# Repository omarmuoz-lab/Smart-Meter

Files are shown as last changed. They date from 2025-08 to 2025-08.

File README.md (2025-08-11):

# Smart Meter – Firmware & PCB Designs

This repository contains all the resources for a custom-built **Smart Meter**, including:

- **Firmware** for the embedded microcontroller.
- **PCB designs** for the hardware implementation.

The project is aimed at real-time measurement of electrical parameters such as voltage, current, active power, reactive power, apparent power, power factor, and energy consumption.

---

## 📂 Repository Structure

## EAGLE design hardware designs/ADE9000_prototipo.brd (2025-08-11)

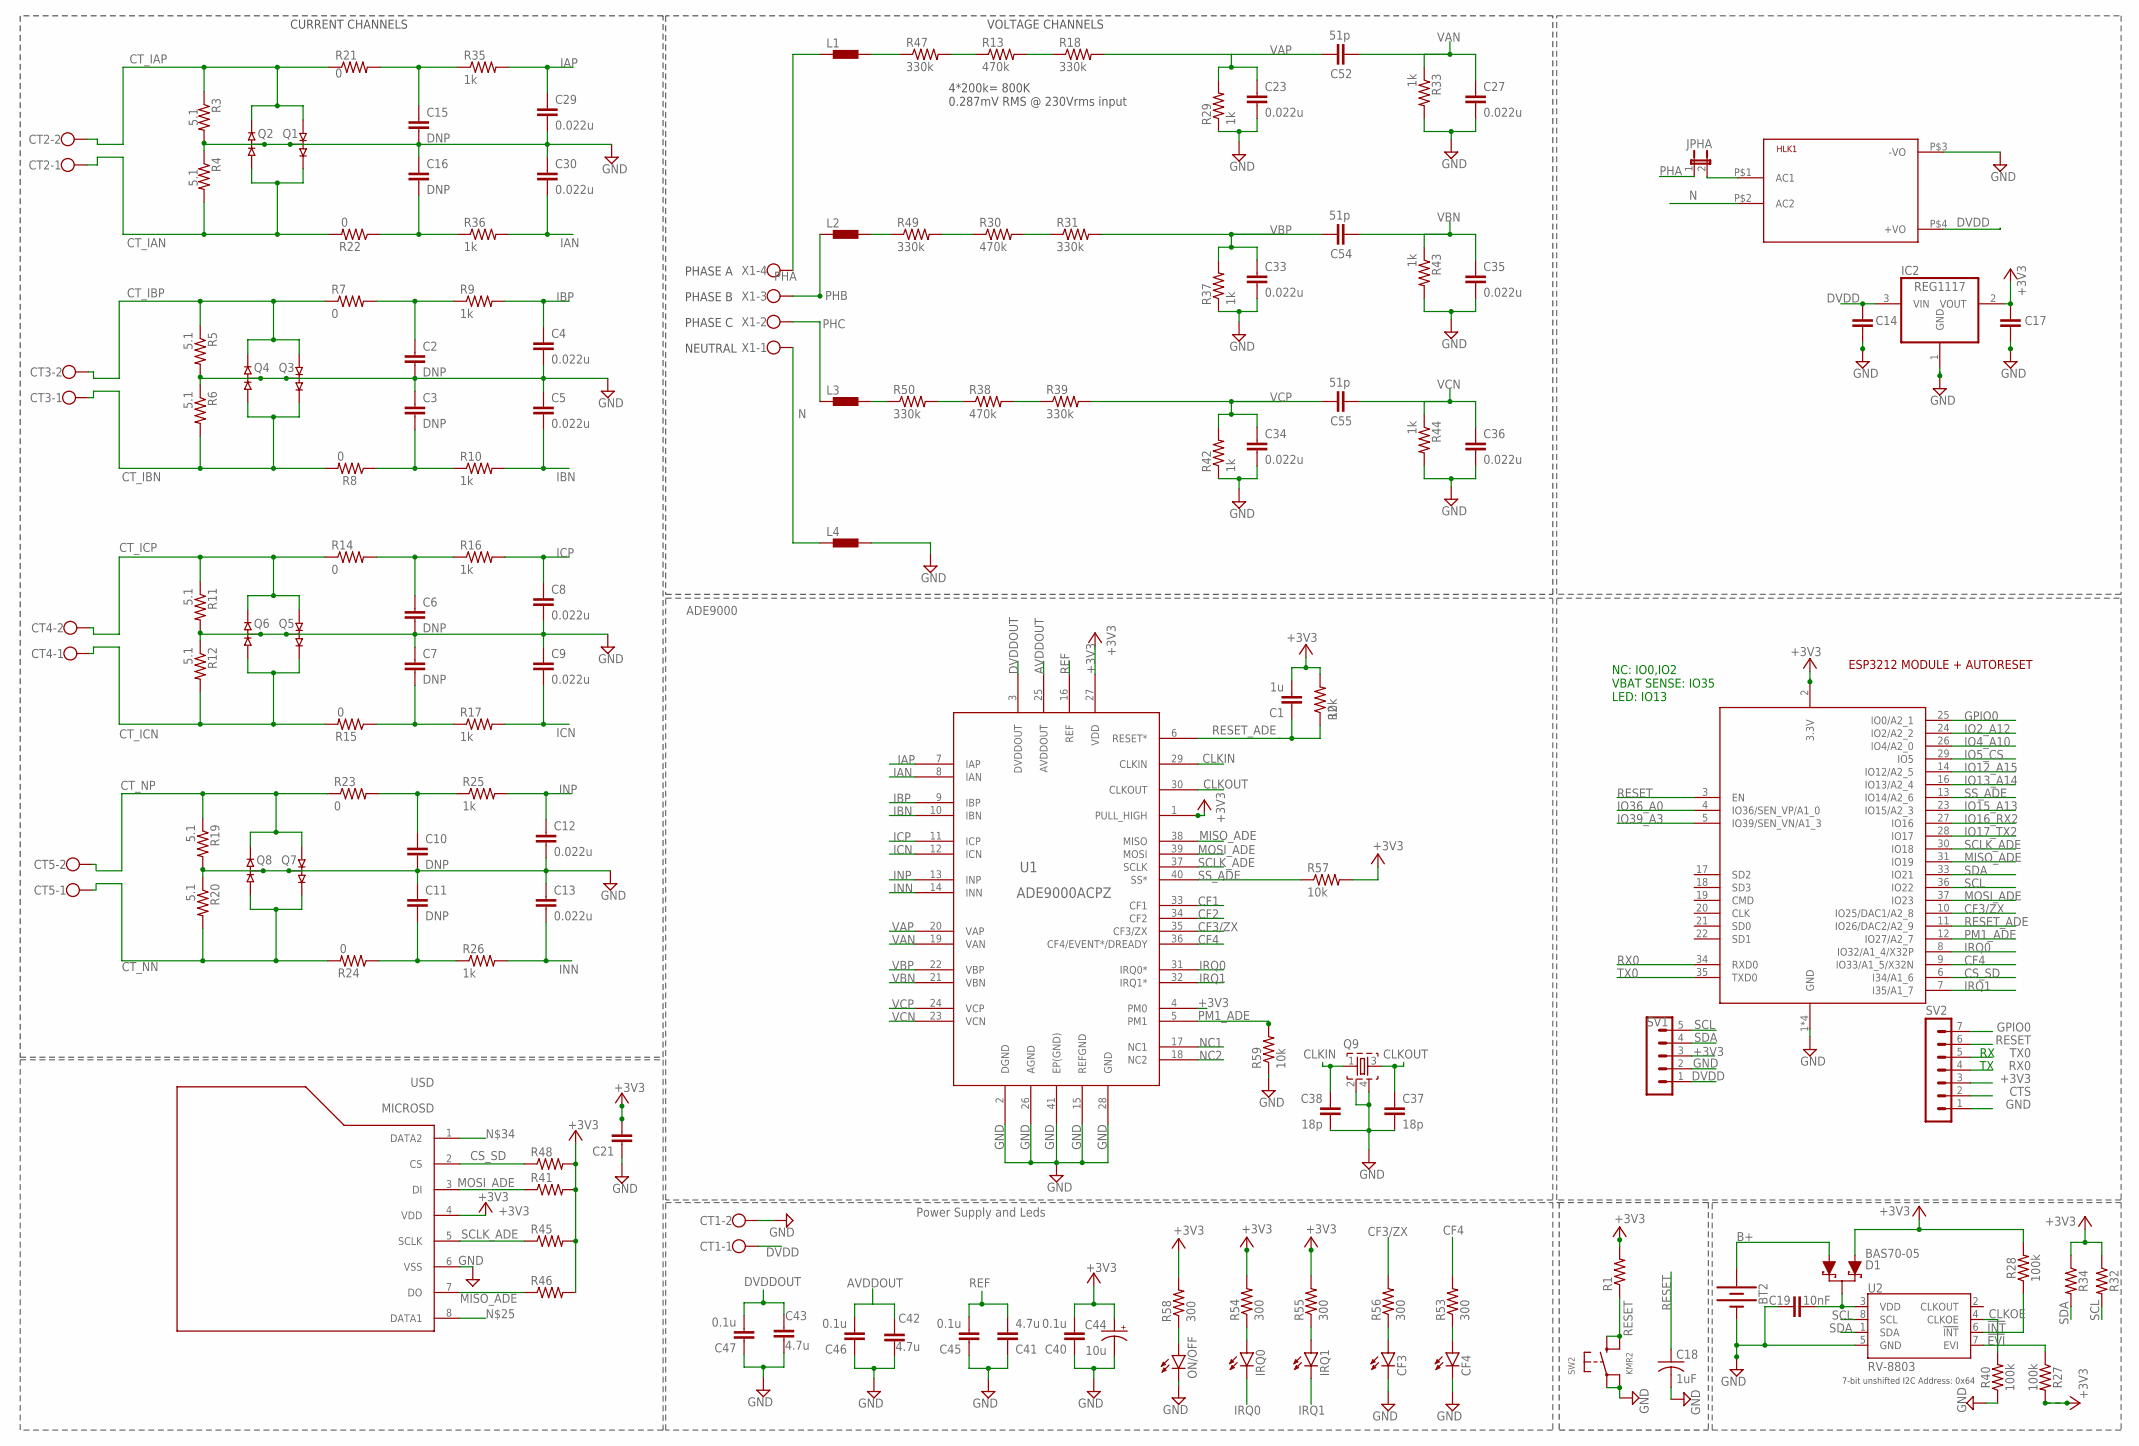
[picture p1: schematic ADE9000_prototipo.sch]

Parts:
BT2: BATTERY-12MM_SMD; BATTCON_12MM
C1: 1u; C0805
C2, C3, C6, C7, C10, C11, C15, C16: DNP; C0805
C4, C5, C8, C9, C12, C13, C23, C29, C30, C33, C34: 0.022u; C0805
C14, C17: C-EUC1206; C1206
C18: 1uF; C0805
C19: 10nF; 0603
C21, C40, C45, C46, C47: 0.1u; C0805
C27, C35, C36: 0.022u; C0603
C37, C38: 18p; C0805
C41, C42, C43: 4.7u; C0805
C44: 10u; E1,8-4
C52, C54, C55: 51p; C0603
CF3, CF4: LEDCHIPLED_1206; CHIPLED_1206
CT1, CT2, CT3, CT4, CT5: W237-102
D1: BAS70-05; SOT23-3
HLK1: HLK-PM013W; HLK-PM01
IC2: REG1117; SOT223
IRQ0, IRQ1: LEDCHIPLED_1206; CHIPLED_1206
JPHA: JP1E; JP1
L1, L2, L3, L4: 1500; M0805; DIGIKEY 490-1048-1-ND
ON/OFF: LEDCHIPLED_1206; CHIPLED_1206
Q1, Q2, Q3, Q4, Q5, Q6, Q7, Q8: MMBD4148SE; SOT23-3; DIGIKEY MMBD4148SECT-ND
Q9: ECS-245.7-12-33Q-JES-TR; SMD_4PIN_3.2X2.1; DIGIKEY XC2178CT-ND
R1, R41, R45, R46, R48: R-US_R0805; R0805
R2, R57, R59: 10k; R0805
R3, R5, R11, R19: 5.1; R0805; MFR_PART_NO_# CPF0805B5R1E1
R4, R6, R12, R20: 5.1; R0805
R7, R8, R14, R15, R21, R22, R23, R24: 0; R0805
R9, R10, R16, R17, R25, R26, R29, R35, R36, R37, R42: 1k; R0805
R13, R30, R38: 470k; R0805
R18, R31, R39, R47, R49, R50: 330k; R0805
R27, R28, R40: 100k; 0603
R32: 4.7k; 0603
R33, R43, R44: 1k; R0603
R34: 4.7KOHM-0603-1/10W-1%; 0603
R53, R54, R55, R56, R58: 300; R0805
SV1: MA05-1
SV2: MA07-1
SW2: KMR2; BTN_KMR2_4.6X2.8
U1: ADE9000ACPZ; CP_40_7; DIGIKEY ADE9000ACPZ-RLCT-ND
U2: RV-8803; RV-3028
USD: MICROSD
X1: W237-4
X4: ESP32_WROOM32_SKINNY; WROOM32_SKINNY

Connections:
!EVI: R27.1, U2.7 (EVI)
!INT: R28.1, U2.6 (!INT)
+3V3: C1.2, C17.1, C21.2, C40.2, C44.+, D1.1 (A), IC2.2 (VOUT), R1.2, R2.2, R27.2, R28.2, R32.1, R34.1, R41.2, R45.2, R46.2, R48.2, R54.2, R55.2, R57.2, R58.2, SV1.3, SV2.3, U1.1 (PULL_HIGH), U1.4 (PM0), U1.27 (VDD), USD.4 (VDD), X4.2 (3.3V)
AVDDOUT: C42.1, C46.2, U1.25 (AVDDOUT)
B+: BT2.PWR@1 (+), D1.2 (A1)
CF1: U1.33 (CF1)
CF2: U1.34 (CF2)
CF3/ZX: R56.2, U1.35 (CF3/ZX), X4.10 (IO25/DAC1/A2_8)
CF4: R53.2, U1.36 (CF4/EVENT*/DREADY), X4.9 (IO33/A1_5/X32N)
CLKIN: C38.1, Q9.1, U1.29 (CLKIN)
CLKOE: R40.2, U2.4 (CLKOE)
CLKOUT: C37.1, Q9.3, U1.30 (CLKOUT)
CS_SD: R48.1, USD.2 (CS), X4.6 (I34/A1_6)
CTS: SV2.2
CT_IAN: CT2.1, Q1.2, Q2.1, R4.2, R22.2
CT_IAP: CT2.2, Q1.1, Q2.2, R3.1, R21.1
CT_IBN: CT3.1, Q3.2, Q4.1, R6.2, R8.2
CT_IBP: CT3.2, Q3.1, Q4.2, R5.1, R7.1
CT_ICN: CT4.1, Q5.2, Q6.1, R12.2, R15.2
CT_ICP: CT4.2, Q5.1, Q6.2, R11.1, R14.1
CT_NN: CT5.1, Q7.2, Q8.1, R20.2, R24.2
CT_NP: CT5.2, Q7.1, Q8.2, R19.1, R23.1
DVDD: C14.1, CT1.1, HLK1.P$4 (+VO), IC2.3 (VIN), SV1.1
DVDDOUT: C43.1, C47.2, U1.3 (DVDDOUT)
GND: BT2.GND (-), C2.2, C3.1, C4.2, C5.1, C6.2, C7.1, C8.2, C9.1, C10.2, C11.1, C12.2, C13.1, C14.2, C15.2, C16.1, C17.2, C18.2, C19.1, C21.1, C23.2, C27.2, C29.2, C30.1, C33.2, C34.2, C35.2, C36.2, C37.2, C38.2, C40.1, C41.1, C42.2, C43.2, C44.-, C45.1, C46.1, C47.1, CF3.C, CF4.C, CT1.2, HLK1.P$3 (-VO), IC2.1 (GND), L4.2, ON/OFF.C, Q1.3, Q2.3, Q3.3, Q4.3, Q5.3, Q6.3, Q7.3, Q8.3, Q9.2, Q9.4, R3.2, R4.1, R5.2, R6.1, R11.2, R12.1, R19.2, R20.1, R29.1, R33.2, R37.1, R40.1, R42.1, R43.2, R44.2, R59.1, SV1.2, SV2.1, SW2.A, SW2.A' (P1), U1.2 (DGND), U1.15 (REFGND), U1.26 (AGND), U1.28 (GND), U1.41 (EP(GND)), U2.5 (GND), USD.6 (VSS), X4.1 (GND), X4.15 (GND), X4.38 (GND), X4.P$1 (GND)
GPIO0: SV2.7, X4.25 (IO0/A2_1)
IAN: C30.2, R36.2, U1.8 (IAN)
IAP: C29.1, R35.2, U1.7 (IAP)
IBN: C5.2, R10.2, U1.10 (IBN)
IBP: C4.1, R9.2, U1.9 (IBP)
ICN: C9.2, R17.2, U1.12 (ICN)
ICP: C8.1, R16.2, U1.11 (ICP)
INN: C13.2, R26.2, U1.14 (INN)
INP: C12.1, R25.2, U1.13 (INP)
IO2_A12: X4.24 (IO2/A2_2)
IO4_A10: X4.26 (IO4/A2_0)
IO5_CS: X4.29 (IO5)
IO12_A15: X4.14 (IO12/A2_5)
IO13_A14: X4.16 (IO13/A2_4)
IO15_A13: X4.23 (IO15/A2_3)
IO16_RX2: X4.27 (IO16)
IO17_TX2: X4.28 (IO17)
IO36_A0: X4.4 (IO36/SEN_VP/A1_0)
IO39_A3: X4.5 (IO39/SEN_VN/A1_3)
IRQ0: IRQ0.C, U1.31 (IRQ0*), X4.8 (IO32/A1_4/X32P)
IRQ1: IRQ1.C, U1.32 (IRQ1*), X4.7 (I35/A1_7)
MISO_ADE: R46.1, U1.38 (MISO), USD.7 (DO), X4.31 (IO19)
MOSI_ADE: R41.1, U1.39 (MOSI), USD.3 (DI), X4.37 (IO23)
N: HLK1.P$2 (AC2), L4.1, X1.1
unnamed: C19.2, D1.3 (C), U2.3 (VDD)
unnamed: R13.1, R47.2
unnamed: C3.2, R8.1, R10.1
unnamed: C2.1, R7.2, R9.1
unnamed: HLK1.P$1 (AC1), JPHA.2
unnamed: L3.2, R50.1
unnamed: L2.2, R49.1
unnamed: C7.2, R15.1, R17.1
unnamed: C6.1, R14.2, R16.1
unnamed: C16.2, R22.1, R36.1
unnamed: C11.2, R24.1, R26.1
unnamed: C10.1, R23.2, R25.1
unnamed: CF3.A, R56.1
unnamed: ON/OFF.A, R58.1
unnamed: IRQ0.A, R54.1
unnamed: IRQ1.A, R55.1
unnamed: CF4.A, R53.1
unnamed: R30.1, R49.2
unnamed: R30.2, R31.1
unnamed: L1.2, R47.1
unnamed: R13.2, R18.1
unnamed: C15.1, R21.2, R35.1
unnamed: R38.1, R50.2
unnamed: R38.2, R39.1
NC1: U1.17 (NC1)
NC2: U1.18 (NC2)
PHA: JPHA.1, L1.1, X1.4
PHB: L2.1, X1.3
PHC: L3.1, X1.2
PM1_ADE: R59.2, U1.5 (PM1), X4.12 (IO27/A2_7)
REF: C41.2, C45.2, U1.16 (REF)
RESET: C18.1, R1.1, SV2.6, SW2.B (S), SW2.B' (S1), X4.3 (EN)
RESET_ADE: C1.1, R2.1, U1.6 (RESET*), X4.11 (IO26/DAC2/A2_9)
RX0: SV2.4, X4.34 (RXD0)
SCL: R32.2, SV1.5, U2.8 (SCL), X4.36 (IO22)
SCLK_ADE: R45.1, U1.37 (SCLK), USD.5 (SCLK), X4.30 (IO18)
SDA: R34.2, SV1.4, U2.1 (SDA), X4.33 (IO21)
SS_ADE: R57.1, U1.40 (SS*), X4.13 (IO14/A2_6)
TX0: SV2.5, X4.35 (TXD0)
VAN: C27.1, C52.1, R33.1, U1.19 (VAN)
VAP: C23.1, C52.2, R18.2, R29.2, U1.20 (VAP)
VBN: C35.1, C54.1, R43.1, U1.21 (VBN)
VBP: C33.1, C54.2, R31.2, R37.2, U1.22 (VBP)
VCN: C36.1, C55.1, R44.1, U1.23 (VCN)
VCP: C34.1, C55.2, R39.2, R42.2, U1.24 (VCP)

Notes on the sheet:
CURRENT CHANNELS
VOLTAGE CHANNELS
4*200k= 800K 0.287mV RMS @ 230Vrms input
PHASE A
PHASE B
PHASE C
NEUTRAL
ADE9000
Power Supply and Leds
ESP3212 MODULE + AUTORESET
NC: IO0,IO2 VBAT SENSE: IO35 LED: IO13
7-bit unshifted I2C Address: 0x64

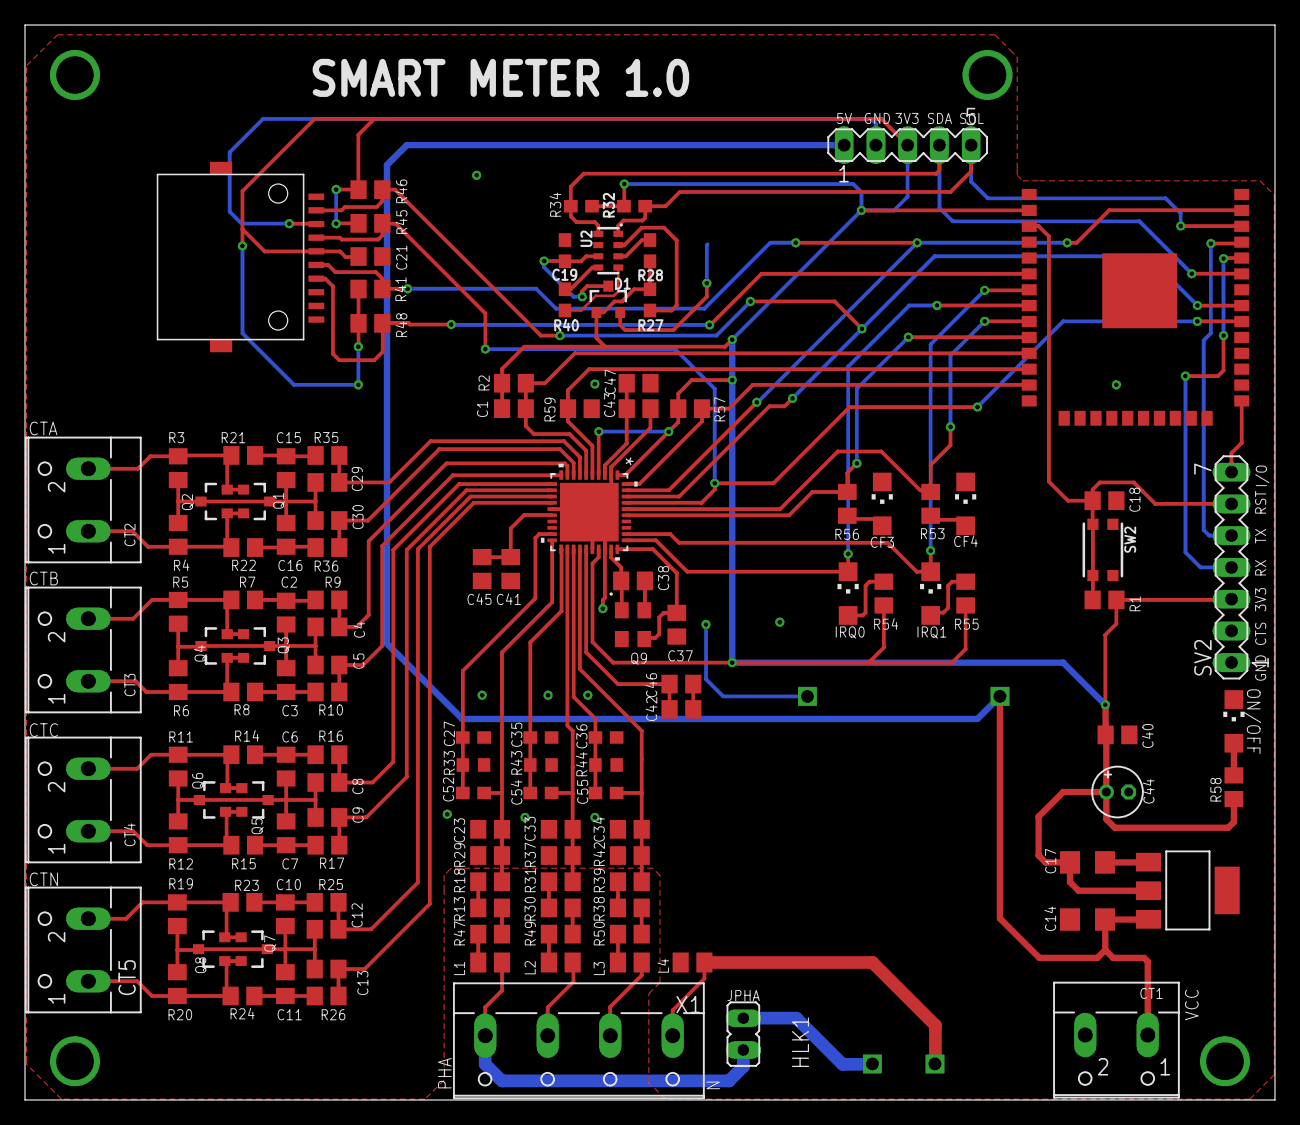
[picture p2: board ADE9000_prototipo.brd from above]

Board: 2 copper layers, 100.0 x 86.0 mm, 134 parts (1 on the bottom side), 79 nets.

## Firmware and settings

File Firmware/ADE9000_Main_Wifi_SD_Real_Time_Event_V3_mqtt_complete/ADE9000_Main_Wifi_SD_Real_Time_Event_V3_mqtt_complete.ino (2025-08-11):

#include "SPI.h"
#include "ADE9000RegMap.h"
#include "ADE9000API.h"
#include "ADE9000CalibrationInputs.h"
#include "arduinoFFT.h"
#include <WiFi.h>
#include <SparkFun_RV8803.h>
#include "esp_task_wdt.h"
#include <PubSubClient.h>
#include <ArduinoJson.h>

#include "FS.h"
#include "SD.h"

/*FFT ANALYSIS*/
#define samplesCoh 512
#define samplingFreqCoh 7680
#define samplesNoncoh 256
#define samplingFreqNoncoh 8000
arduinoFFT FFT = arduinoFFT();
/*Coherent FFT variables*/
double arrayCohA[samplesCoh] = {};
double arrayCohB[samplesCoh] = {};
double arrayCohC[samplesCoh] = {};
double sigA[samplesCoh] = {};
double sigB[samplesCoh] = {};
double sigC[samplesCoh] = {};
double imagCohA[samplesCoh] = {};
double imagCohB[samplesCoh] = {};
double imagCohC[samplesCoh] = {};
double binCohA[samplesCoh] = {};
double binCohB[samplesCoh] = {};
double binCohC[samplesCoh] = {};
double binCohSendA[64] = {};
double binCohSendB[64] = {};
double binCohSendC[64] = {};
String sampleTime, completeSample;
String electricSamplesA, electricSamplesB, electricSamplesC;

/*Basic initializations*/
ADE9000Class ade9000;

#define SPI_SPEED 5000000     //SPI Speed
#define CS_PIN 14             //8-->Arduino Zero. 16-->ESP8266
#define ADE9000_RESET_PIN 26  //Reset Pin on HW
#define PM_1 27               //PM1 Pin: 4-->Arduino Zero. 15-->ESP8266
#define EGY_REG_SIZE 6
int c = 0;
bool flag = false;

#define EGY_INTERRUPT_MASK0 0x00000001
#define EGY_INTERRUPT_MASK1 0x00000000

/*Structure decleration */
struct ActivePowerRegs powerRegs;             // Declare powerRegs of type ActivePowerRegs to store Active Power Register data
struct CurrentRMSRegs curntRMSRegs;           //Current RMS
struct VoltageRMSRegs vltgRMSRegs;            //Voltage RMS
struct VoltageTHDRegs voltageTHDRegsnValues;  //Voltage THD
struct CurrentTHDRegs CurrentTHDRegsnValues;
struct ResampledWfbDataNoncoh resampledDataNoncoh;  // Resampled Data
struct ResampledWfbDataCoh resampledData;
struct PeriodRegs freqRegs;  //period
struct VoltageRMSRegs tVrms;
struct CurrentRMSRegs tIrms;
struct ActivePowerRegs watts;
struct ApparentPowerRegs VA;
struct ReactivePowerRegs VAR;
struct WatthrRegValue wattHr;
struct VARhrRegValue varHr;
struct PfRegValue pf;
struct PowerFactorRegs pf2;
struct FundCurrentRMSRegs fIrms;
struct FundVoltageRMSRegs fVrms;
/*Function Decleration*/
void readRegisterData(void);
void readResampledData(void);
void resetADE9000(void);
/*Calibration values decleration*/
int32_t xIgain_registers[3] = { -175309, -80350, 795949};
int32_t xIgain_register_address[3] = {ADDR_AIGAIN, ADDR_BIGAIN, ADDR_CIGAIN};
int32_t xVgain_registers[3] = {90497, 85826, -270434};
int32_t xVgain_register_address[3] = {ADDR_AVGAIN, ADDR_BVGAIN, ADDR_CVGAIN};
int32_t xIoffset_registers[6] = { -314, -1144, -2255, 4, -816, -1955};
int32_t xIoffset_register_address[6] = {ADDR_AIRMSOS, ADDR_BIRMSOS, ADDR_CIRMSOS, ADDR_AIFRMSOS, ADDR_BIFRMSOS, ADDR_CIFRMSOS}; //order [AIGAIN, BIGAIN, CIGAIN, NIGAIN]
int32_t xVoffset_registers[6] = {604060, 1075923, 1483149, 606638, 1080576, 1486636};
int32_t xVoffset_register_address[6] = {ADDR_AVRMSOS, ADDR_BVRMSOS, ADDR_CVRMSOS, ADDR_AVFRMSOS, ADDR_BVFRMSOS, ADDR_CVFRMSOS}; //order [AIGAIN, BIGAIN, CIGAIN, NIG
int32_t xPhcal_registers[3] = { -41807055, -42324166, -44065521};
int32_t xPhcal_register_address[3] = {ADDR_APHCAL0, ADDR_BPHCAL0, ADDR_CPHCAL0};
//int32_t xPgain_registers[3] = {-154816,115776 ,-630616};
int32_t xPgain_registers[3] = {336500, 1105465, 1554645};
int32_t xPgain_register_address[3] = {ADDR_APGAIN, ADDR_BPGAIN, ADDR_CPGAIN};
int32_t xPoffset1_registers[6] = {48, 38, 32, 98, 85, 76};
int32_t xPoffset_register_address[6] = {ADDR_AWATTOS, ADDR_BWATTOS, ADDR_CWATTOS, ADDR_AFWATTOS, ADDR_BFWATTOS, ADDR_CFWATTOS}; //order [AVGAIN, BVGAIN, CVGAIN, NVGAIN]
int32_t xPoffset2_registers[6] = {46, 37, 35, 127, 116, 114};
int32_t xPoffsetVAR_register_address[6] = {ADDR_AVAROS, ADDR_BVAROS, ADDR_CVAROS, ADDR_AFVAROS, ADDR_BFVAROS, ADDR_CFVAROS};


int32_t accumulatedActiveEnergy_registers[EGY_REG_SIZE];
int32_t xWATTHRHI_registers_address[6] = { ADDR_AWATTHR_HI, ADDR_BWATTHR_HI, ADDR_CWATTHR_HI, ADDR_AFWATTHR_HI, ADDR_BFWATTHR_HI, ADDR_CFWATTHR_HI };
int32_t accumulatedReactiveEnergy_registers[EGY_REG_SIZE];
int32_t xVARHRHI_registers_address[6] = { ADDR_AVARHR_HI, ADDR_BVARHR_HI, ADDR_CVARHR_HI, ADDR_AFVARHR_HI, ADDR_BFVARHR_HI, ADDR_CFVARHR_HI };


float newS, lastS = 0.00;
double wattHrASum = 0.00, wattHrBSum = 0.00, wattHrCSum = 0.00;
double varHrASum = 0.00, varHrBSum = 0.00, varHrCSum = 0.00;
void writeRegisters(int32_t *, int32_t *);
bool lastPage = false;
bool cohFlag = false;
bool noncohFlag = false;
uint32_t load, loadA, loadB, loadC;
/*Variables phase A*/
float freqA, vRmsA, iRmsA, wattA, apA, rpA, PfA, iFundRmsA, vFundRmsA, CurrentTHDValue_A;
float freqB, vRmsB, iRmsB, wattB, apB, rpB, PfB, iFundRmsB, vFundRmsB, CurrentTHDValue_B;
float freqC, vRmsC, iRmsC, wattC, apC, rpC, PfC, iFundRmsC, vFundRmsC, CurrentTHDValue_C;
double wattHrPerSecA = 0.00, wattHrPerSecB = 0.00, wattHrPerSecC = 0.00;
double varHrPerSecA = 0.00, varHrPerSecB = 0.00, varHrPerSecC = 0.00;
bool energyReady = false, harmonicsReady = false, isLoadA = false, isLoadB = false, isLoadC = false, sendingHarmonics = false, firsTimeHarmo = true, online = true, event_sent = true;
int counterSend = 1, lastSecond = 0, counter = 0;
char inputChar[1];
String inputString;
String inputWebPage;

String total[100][1];
String sampleTimeB;
String sampleTimeC;

//variables of event detection
#define mean_window_length 20
#define num_changes 50
#define record_window 500
double mean_window_array[mean_window_length], threshold = 0.300, threshold_min = 0.100, deviation, rising, falling;
double slide_window_active[mean_window_length], slide_window_reactive[mean_window_length], slide_window_apparent[mean_window_length], slide_window_ifund[mean_window_length];
int change_points[num_changes], positive_changes[num_changes], negative_changes[num_changes];
double positive_rec[record_window], positive_rec_finished[record_window], negative_rec[record_window], negative_rec_finished[record_window];
double positive_active[record_window], negative_active[record_window], positive_reactive[record_window], negative_reactive[record_window], positive_apparent[record_window], negative_apparent[record_window], positive_ifund[record_window], negative_ifund[record_window];
int counterPositive = 0, counterNegative = 0;
bool positive_flag = false, recording_positive = false, negative_flag = false, recording_negative = false, saved = false;
float mean_window = 0.00;
int sample_counter = 0, events_counter = 0, positive_counter = 0, negative_counter = 0, done_positive = 0, done_negative = 0;

const char *ssid = "INFINITUM3E94";  // Enter your WiFi name
const char *password = "g2EXf7D9xy";     // Enter WiFi password
//const char *ssid = "omarcell"; // Enter your WiFi name
//const char *password = "omarcell";  // Enter WiFi password

// Configuración del broker MQTT
const char *mqtt_broker = "broker.emqx.io";
const char *topic = "smartMeterTest";
const char *mqtt_username = "emqx";
const char *mqtt_password = "public";
const int mqtt_port = 1883;

WiFiClient espClient;
PubSubClient client(espClient);

RV8803 rtc;
int cont = 0;
void setup() {
  Serial.begin(500000);
  Serial.println("");
  if (!SD.begin(16)) {
    Serial.println("Card Mount Failed");
    return;
  }
  uint8_t cardType = SD.cardType();

  if (cardType == CARD_NONE) {
    Serial.println("No SD card attached");
    return;
  }

  Serial.print("SD Card Type: ");
  if (cardType == CARD_MMC) {
    Serial.println("MMC");
  } else if (cardType == CARD_SD) {
    Serial.println("SDSC");
  } else if (cardType == CARD_SDHC) {
    Serial.println("SDHC");
  } else {
    Serial.println("UNKNOWN");
  }

  uint64_t cardSize = SD.cardSize() / (1024 * 1024);
  Serial.printf("SD Card Size: %lluMB\n", cardSize);

  Wire.begin();
  Serial.println("*********************ADE9000 SETUP***************************\n ");
  ade9000.SPI_Write_16(ADDR_RUN, 0);
  pinMode(PM_1, OUTPUT);    //Set PM1 pin as output
  digitalWrite(PM_1, LOW);  //Set PM1 select pin low for PSM0 mode
  pinMode(ADE9000_RESET_PIN, OUTPUT);
  digitalWrite(ADE9000_RESET_PIN, HIGH);
  resetADE9000();
  ade9000.SPI_Init(SPI_SPEED, CS_PIN);  //Initialize SPI
  ade9000.SetupADE9000();               //Initialize ADE9000 registers according to values in ADE9000API.
  Serial.print("RUN Register: ");
  ade9000.SPI_Write_32(ADDR_STATUS0, 0xFFFFFFFF);
  ade9000.SPI_Write_32(ADDR_STATUS1, 0xFFFFFFFF);
  pinMode(32, INPUT_PULLUP);
  pinMode(15, OUTPUT);
  attachInterrupt(digitalPinToInterrupt(32), updateEnergyRegisterFromInterrupt, FALLING);
  ade9000.SPI_Write_32(ADDR_STATUS0, 0xFFFFFFFF);
  /*calibration*/
  writeRegisters(xIgain_register_address, xIgain_registers);
  writeRegisters(xVgain_register_address, xVgain_registers);
  writeRegisters(xIoffset_register_address, xIoffset_registers);
  writeRegisters(xVoffset_register_address, xVoffset_registers);
  writeRegisters(xPhcal_register_address, xPhcal_registers);
  writeRegisters(xPgain_register_address, xPgain_registers);
  writeRegisters(xPoffset_register_address, xPoffset1_registers);
  writeRegisters(xPoffsetVAR_register_address, xPoffset2_registers);
  //coherentHarmonics();



  Serial.println("*********************Wifi and Broker conexion******************");
  WiFi.begin(ssid, password);
  while (WiFi.status() != WL_CONNECTED) {
    delay(500);
    Serial.println("Connecting to WiFi..");
    counter++;
    if (counter > 10) {
      break;
    }
  }
  Serial.println("Connected to the WiFi network");
  if (rtc.begin() == false) {
    Serial.println("Something went wrong, check wiring");
  } else {
    Serial.println("RTC online!");
    setRtcNptTime();
    rtc.updateTime();
    sampleTime = (String)rtc.getYear() + ":" + (String)(rtc.getMonth() + 1) + ":" + (String)rtc.getDate() + ":" + (String)(rtc.getHours()) + ":" + (String)rtc.getMinutes() + ":" + (String)rtc.getSeconds() + ":" + (String)(rtc.getHundredths() * 10) + ",";
    Serial.println(sampleTime);
  }

  //connecting to a mqtt broker
  client.setServer(mqtt_broker, mqtt_port);
  client.setCallback(callback);
  while (!client.connected()) {
    String client_id = "esp32-client-";
    client_id += String(WiFi.macAddress());
    Serial.printf("The client %s connects to the public MQTT broker\n", client_id.c_str());
    if (client.connect(client_id.c_str(), mqtt_username, mqtt_password)) {
      Serial.println("Public EMQX MQTT broker connected");
      online = true;
    } else {
      Serial.print("failed with state ");
      Serial.print(client.state());
      delay(2000);
    }
  }
  client.subscribe("webPageStatus");
  client.publish("reconect", "reconecting");
}

void callback(char *topic, byte *payload, unsigned int length) {
  Serial.print("Message arrived in topic: ");
  Serial.println(topic);
  Serial.print("Message:");
  firsTimeHarmo = true;
  for (int i = 0; i < length; i++) {
    Serial.print((char) payload[i]);
    inputChar[i] = (char)payload[i];
  }

  Serial.println();
  Serial.println("-----------------------");
}
float actualTime, lastTime = 0.00;
float actualTimeMillis, lastTimeMillis, lastTimeMillisSend, delta = 10;
void loop() {
  yield();
  checkedInterrupt();
  connect_wifi();
  if (!client.connected()) {
    online = false;
    connect_mqtt();        // Reconectar si la conexión se pierde
  }
  client.loop();           // Mantener la conexión MQTT
  online = true;
  if ((String)rtc.getYear() == "2000") {
    if (rtc.begin() == false) {
      //Serial.println("Something went wrong, check wiring");
    } else {
      //Serial.println("RTC online!");
      setRtcNptTime();
      rtc.updateTime();
      sampleTime = (String)rtc.getYear() + ":" + (String)(rtc.getMonth() + 1) + ":" + (String)rtc.getDate() + ":" + (String)(rtc.getHours()) + ":" + (String)rtc.getMinutes() + ":" + (String)rtc.getSeconds() + ":" + (String)(rtc.getHundredths() * 10) + ",";
      //Serial.println(sampleTime);
    }
  }
  load = (ade9000.SPI_Read_32(ADDR_PHNOLOAD));
  loadA = load & 0x0000003F;
  loadB = load & 0x00000FC0;
  loadC = load & 0x0003F000;
  ade9000.ReadPeriodRegsnValues(&freqRegs);
  ade9000.ReadVoltageRMSRegs(&tVrms);
  ade9000.ReadCurrentRMSRegs(&tIrms);
  ade9000.ReadActivePowerRegs(&watts);
  ade9000.ReadApparentPowerRegs(&VA);
  ade9000.ReadReactivePowerRegs(&VAR);
  ade9000.ReadPfValue(&pf);
  ade9000.ReadPowerFactorRegsnValues(&pf2);
  ade9000.ReadFundCurrentRMSRegs(&fIrms);
  ade9000.ReadFundVoltageRMSRegs(&fVrms);
  ade9000.ReadCurrentTHDRegsnValues(&CurrentTHDRegsnValues);

  if (loadA == 0x0000003F)  //0x0000003F
  {
    isLoadA = false;
    Serial.println("NO-load A");
    freqA = freqRegs.FrequencyValue_A;
    vRmsA = tVrms.vRmsA;
    iRmsA = 0;
    wattA = 0;
    apA = 0;
    rpA = 0;
    PfA = 0;
    iFundRmsA = 0;
    vFundRmsA = 0;
    CurrentTHDValue_A = 0;
  } else {
    isLoadA = true;
    freqA = freqRegs.FrequencyValue_A;
    vRmsA = tVrms.vRmsA;
    iRmsA = tIrms.iRmsA;
    wattA = watts.wattA;
    apA = VA.apA;
    rpA = VAR.rpA;
    PfA = pf.PfA;
    iFundRmsA = fIrms.iFundRmsA;
    vFundRmsA = fVrms.vFundRmsA;
    CurrentTHDValue_A = CurrentTHDRegsnValues.CurrentTHDValue_A;
  }
  if (loadB == 0x00000FC0) {
    isLoadB = false;
    Serial.println("NO-load B");
    freqB = freqRegs.FrequencyValue_B;
    vRmsB = tVrms.vRmsB;
    iRmsB = 0;
    wattB = 0;
    apB = 0;
    rpB = 0;
    PfB = 0;
    iFundRmsB = 0;
    vFundRmsB = 0;
    CurrentTHDValue_B = 0;
  } else {
    isLoadB = true;
    freqB = freqRegs.FrequencyValue_B;
    vRmsB = tVrms.vRmsB;
    iRmsB = tIrms.iRmsB;
    wattB = watts.wattB;
    apB = VA.apB;
    rpB = VAR.rpB;
    PfB = pf.PfB;
    iFundRmsB = fIrms.iFundRmsB;
    vFundRmsB = fVrms.vFundRmsB;
    CurrentTHDValue_B = CurrentTHDRegsnValues.CurrentTHDValue_B;
  }
  if (loadC == 0x0003F000) {
    isLoadC = false;
    Serial.println("NO-load C");
    freqC = freqRegs.FrequencyValue_C;
    vRmsC = tVrms.vRmsC;
    iRmsC = 0;
    wattC = 0;
    apC = 0;
    rpC = 0;
    PfC = 0;
    iFundRmsC = 0;
    vFundRmsC = 0;
    CurrentTHDValue_C = 0;
  } else {
    isLoadC = true;
    freqC = freqRegs.FrequencyValue_C;
    vRmsC = tVrms.vRmsC;
    iRmsC = tIrms.iRmsC;
    wattC = watts.wattC;
    apC = VA.apC;
    rpC = VAR.rpC;
    PfC = pf.PfC;
    iFundRmsC = fIrms.iFundRmsC;
    vFundRmsC = fVrms.vFundRmsC;
    CurrentTHDValue_C = CurrentTHDRegsnValues.CurrentTHDValue_C;
  }

  if (PfA > 0.9998) {
    PfA = 1.00;
    apA = wattA;
  }
  if (PfB > 0.9998) {
    PfB = 1.00;
    apB = wattB;
  }
  if (PfC > 0.9998) {
    PfC = 1.00;
    apC = wattC;
  }


  rtc.updateTime();
  actualTimeMillis = rtc.getHundredths() * 10;

  if (abs(actualTimeMillis - lastTimeMillis) >= delta)
  {
    checkedInterrupt();
    sampleTime = (String)rtc.getYear() + ":" + (String)(rtc.getMonth() + 1) + ":" + (String)rtc.getDate() + ":" + (String)(rtc.getHours()) + ":" + (String)rtc.getMinutes() + ":" + (String)rtc.getSeconds() + ":" + (String)(rtc.getHundredths() * 10) + ",";
    detect_events((iRmsA + iRmsB), (wattA + wattB), (rpA + rpB), (apA + apB), (iFundRmsA + iFundRmsB), sampleTime);
    sample_counter++;
    //electricSamplesA = (String)freqRegs.FrequencyValue_A + "," + (String)tVrms.vRmsA + "," + (String)iRmsA + "," + (String)(wattA + wattB) + "," + (String)(apA + apB) + "," + (String)(rpA / 1000) + "," + (String)(PfA) + "," + (String)(iFundRmsA) + "," + (String)(vFundRmsA) + "," + (String)(CurrentTHDRegsnValues.CurrentTHDValue_A) + ",";
    //electricSamplesB = (String)tVrms.vRmsB + "," + (String)iRmsB + "," + (String)(wattB / 1000) + "," + (String)(apB / 1000) + "," + (String)(rpB / 1000) + "," + (String)(PfB) + "," + (String)(iFundRmsB) + "," + (String)(vFundRmsB) + "," + (String)(CurrentTHDRegsnValues.CurrentTHDValue_B) + ",";
    //electricSamplesC = (String)tVrms.vRmsC + "," + (String)iRmsC + "," + (String)(wattC / 1000) + "," + (String)(apC / 1000) + "," + (String)(rpC / 1000) + "," + (String)(PfC) + "," + (String)(iFundRmsC) + "," + (String)(vFundRmsC) + "," + (String)(CurrentTHDRegsnValues.CurrentTHDValue_C);
    //completeSample += "\n" + sampleTime  + electricSamplesA + electricSamplesB + electricSamplesC;
    //Serial.println(electricSamplesA);
    lastTimeMillis = actualTimeMillis;
  }
  if (abs(actualTimeMillis - lastTimeMillisSend) >= 600 && *inputChar == 'b' && positive_flag == false && negative_flag == false && event_sent == true)
  {
    sampleTime = (String)rtc.getYear() + "," + (String)rtc.getMonth() + "," + (String)rtc.getDate() + "," + (String)(rtc.getHours() - 1) + "," + (String)rtc.getMinutes() + "," + (String)rtc.getSeconds() + "," + (String)(rtc.getHundredths() * 10);
    sendPhaJson("centralPhA", freqA, vRmsA, iRmsA, wattA, apA, rpA, vFundRmsA, iFundRmsA, PfA, CurrentTHDValue_A, sampleTime);
    sendPhaJson("centralPhB", freqB, vRmsB, iRmsB, wattB, apB, rpB, vFundRmsB, iFundRmsB, PfB, CurrentTHDValue_B, sampleTime);
    sendPhaJson("centralPhC", freqC, vRmsC, iRmsC, wattC, apC, rpC, vFundRmsC, iFundRmsC, PfC, CurrentTHDValue_C, sampleTime);
    lastTimeMillisSend = actualTimeMillis;
  }

  if (lastSecond != (int)rtc.getSeconds() && recording_positive == false && recording_negative == false)
  {
    sampleTime = (String)rtc.getYear() + "," + (String)rtc.getMonth() + "," + (String)rtc.getDate() + "," + (String)(rtc.getHours() - 1) + "," + (String)rtc.getMinutes() + "," + (String)rtc.getSeconds() + "," + (String)(rtc.getHundredths() * 10);
    sendsSumPower("sumPower", wattA, wattB, wattC, apA, apB, apC, rpA, rpB, rpC, sampleTime);
    lastSecond = (int)rtc.getSeconds();
  }
  if (energyReady == true)
  {
    if (ade9000.SPI_Read_16(ADDR_EGY_TIME) != ADE9000_EGY_TIME) {
      ade9000.SPI_Write_16(ADDR_EGY_TIME, ADE9000_EGY_TIME);
      Serial.println("Interrupt Restored");
    }
    IRAM_ATTR ade9000.ReadWatthrRegsnValue(&wattHr);
    IRAM_ATTR ade9000.ReadVARhrRegsnValue(&varHr);
    wattHrPerSecA = wattHr.wattHrA;
    wattHrPerSecB = wattHr.wattHrB;
    wattHrPerSecC = wattHr.wattHrC;

    varHrPerSecA = varHr.VARHrA;
    varHrPerSecB = varHr.VARHrB;
    varHrPerSecC = varHr.VARHrC;

    if (online == false) {
      wattHrASum += wattHrPerSecA;
      wattHrBSum += wattHrPerSecB;
      wattHrCSum += wattHrPerSecC;

      varHrASum += varHrPerSecA;
      varHrBSum += varHrPerSecB;
      varHrCSum += varHrPerSecC;


      wattHrPerSecA = wattHrASum;
      wattHrPerSecB = wattHrBSum;
      wattHrPerSecC = wattHrCSum;
      varHrPerSecA = varHrASum;
      varHrPerSecB = varHrBSum;
      varHrPerSecC = varHrCSum;
    } else {
      wattHrASum = 0;
      wattHrBSum = 0;
      wattHrCSum = 0;
      varHrASum = 0;
      varHrBSum = 0;
      varHrCSum = 0;
    }
    sampleTime = (String)rtc.getYear() + "," + (String)rtc.getMonth() + "," + (String)rtc.getDate() + "," + (String)(rtc.getHours() - 1) + "," + (String)rtc.getMinutes() + "," + (String)rtc.getSeconds() + "," + (String)(rtc.getHundredths() * 10);
    sendEnergyJson(sampleTime);
    energyReady = false;
  }
}
void resetADE9000(void) {
  yield();
  digitalWrite(ADE9000_RESET_PIN, LOW);
  delay(50);
  digitalWrite(ADE9000_RESET_PIN, HIGH);
  delay(1000);
  Serial.println("\nReset Done");
}

void writeRegisters(int32_t *regAddress, int32_t *valueAddress) {
  for (int c = 0; c < sizeof(regAddress) - 1; c++) {

    if (c == 0) {
      Serial.print("\nWriting Registers: ");
    }
    ade9000.SPI_Write_32(regAddress[c], valueAddress[c]);
    Serial.print(regAddress[c], HEX);
    Serial.print("|");
    Serial.print((signed)ade9000.SPI_Read_32(regAddress[c]));
    Serial.print("|");
  }
}

IRAM_ATTR void updateEnergyRegisterFromInterrupt() {

  energyReady = true;
  IRAM_ATTR ade9000.SPI_Write_32(ADDR_STATUS0, 0xFFFFFFFF);
}


void setRtcNptTime() {

  const char *ntpServer = "pool.ntp.org";
  const long gmtOffset_sec = 0;
  const int daylightOffset_sec = 0;
  int sec, minute, hour, date, month, year, weekday;
  struct tm timeinfo;

  configTime(gmtOffset_sec, daylightOffset_sec, ntpServer);
  if (!getLocalTime(&timeinfo)) {
    Serial.println("Failed to obtain time");
    return;
  }
  sec = timeinfo.tm_sec;
  minute = timeinfo.tm_min;
  //Serial.println(minute);
  hour = (timeinfo.tm_hour);
  date = timeinfo.tm_mday;
  month = timeinfo.tm_mon;
  year = timeinfo.tm_year + 1900;
  if (rtc.setTime(sec, minute, hour, weekday, date, month, year) == false) {
    Serial.println("Something went wrong setting the time");
  }

  rtc.set24Hour();
}




void appendFile(fs::FS & fs, const char *path, const char *message) {

  SPI.endTransaction();
  SD.begin(16);

  File file = fs.open(path, FILE_APPEND);
  if (!file) {
    Serial.println("Failed to open file for appending");
    return;
  }
  if (file.print(message)) {
    //Serial.println("Message appended");
  } else {
    //Serial.println("Append failed");
  }
  file.close();
  SPI.endTransaction();
  ade9000.SPI_Init(SPI_SPEED, CS_PIN);  //Initialize SPI
}
double first_positive = 0, first_negative = 0;
bool false_event = false;
String time_event = "";
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

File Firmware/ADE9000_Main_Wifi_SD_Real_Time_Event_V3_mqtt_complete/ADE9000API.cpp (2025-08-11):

/*
  ADE9000API.cpp - Library for ADE9000/ADE9078 - Energy and PQ monitoring AFE
  Date: 3-16-2017
*/
/****************************************************************************************************************
  Includes
***************************************************************************************************************/

#include <Arduino.h>
#include <SPI.h>
#include "ADE9000API.h"
#include <Wire.h>

/*EEPROM data structure*/
uint32_t ADE9000_CalibrationRegAddress[CALIBRATION_CONSTANTS_ARRAY_SIZE] = {ADDR_AIGAIN, ADDR_BIGAIN, ADDR_CIGAIN, ADDR_NIGAIN, ADDR_AVGAIN, ADDR_BVGAIN, ADDR_CVGAIN, ADDR_APHCAL0, ADDR_BPHCAL0, ADDR_CPHCAL0, ADDR_APGAIN, ADDR_BPGAIN, ADDR_CPGAIN};
uint32_t ADE9000_Eeprom_CalibrationRegAddress[CALIBRATION_CONSTANTS_ARRAY_SIZE] = {ADDR_AIGAIN_EEPROM, ADDR_BIGAIN_EEPROM, ADDR_CIGAIN_EEPROM, ADDR_NIGAIN_EEPROM, ADDR_AVGAIN_EEPROM, ADDR_BVGAIN_EEPROM, ADDR_CVGAIN_EEPROM, ADDR_APHCAL0_EEPROM, ADDR_BPHCAL0_EEPROM, ADDR_CPHCAL0_EEPROM, ADDR_APGAIN_EEPROM, ADDR_BPGAIN_EEPROM, ADDR_CPGAIN_EEPROM};

ADE9000Class::ADE9000Class()
{

}

/*
  Description: Initializes the ADE9000. The initial settings for registers are defined in ADE9000API.h header file
  Input: Register settings in header files
  Output:
*/

void ADE9000Class::SetupADE9000(void)
{
  Serial.println("\nSetting up in library....");
  SPI_Write_16(ADDR_PGA_GAIN, ADE9000_PGA_GAIN);
  SPI_Write_32(ADDR_CONFIG0, ADE9000_CONFIG0);
  SPI_Write_16(ADDR_CONFIG1, ADE9000_CONFIG1);
  SPI_Write_16(ADDR_CONFIG2, ADE9000_CONFIG2);
  SPI_Write_16(ADDR_CONFIG3, ADE9000_CONFIG3);
  SPI_Write_16(ADDR_ACCMODE, ADE9000_ACCMODE);
  SPI_Write_16(ADDR_TEMP_CFG, ADE9000_TEMP_CFG);
  SPI_Write_16(ADDR_ZX_LP_SEL, ADE9000_ZX_LP_SEL);
  SPI_Write_32(ADDR_MASK0, ADE9000_MASK0);
  SPI_Write_32(ADDR_MASK1, ADE9000_MASK1);
  SPI_Write_32(ADDR_EVENT_MASK, ADE9000_EVENT_MASK);
  //SPI_Write_16(ADDR_WFB_CFG, ADE9000_WFB_CFG);
  SPI_Write_32(ADDR_VLEVEL, ADE9000_VLEVEL);
  SPI_Write_32(ADDR_DICOEFF, ADE9000_DICOEFF);
  SPI_Write_16(ADDR_EGY_TIME, ADE9000_EGY_TIME);
  SPI_Write_16(ADDR_EP_CFG, ADE9000_EP_CFG);   //Energy accumulation ON
  SPI_Write_16(ADDR_RUN, ADE9000_RUN_ON);  //DSP ON
}

/*
  Description: Initializes the arduino SPI port using SPI.h library
  Input: SPI speed, chip select pin
  Output:-
*/

void ADE9000Class::SPI_Init(uint32_t SPI_speed , uint8_t chipSelect_Pin)
{
  SPI.begin();    //Initiate SPI port
  SPI.beginTransaction(SPISettings(SPI_speed, MSBFIRST, SPI_MODE0));  //Setup SPI parameters
  pinMode(chipSelect_Pin, OUTPUT);    //Set Chip select pin as output
  digitalWrite(chipSelect_Pin, HIGH);   //Set Chip select pin high

  _chipSelect_Pin = chipSelect_Pin;
}

/*
  Description: Writes 16bit data to a 16 bit register.
  Input: Register address, data
  Output:-
*/

void ADE9000Class:: SPI_Write_16(uint16_t Address , uint16_t Data )
{
  uint16_t temp_address;

  digitalWrite(_chipSelect_Pin, LOW);
  temp_address = ((Address << 4) & 0xFFF0); //shift address  to align with cmd packet
  SPI.transfer16(temp_address);
  SPI.transfer16(Data);

  digitalWrite(_chipSelect_Pin, HIGH);
}

/*
  Description: Writes 32bit data to a 32 bit register.
  Input: Register address, data
  Output:-
*/

void ADE9000Class:: SPI_Write_32(uint16_t Address , uint32_t Data )
{
  uint16_t temp_address;
  uint16_t temp_highpacket;
  uint16_t temp_lowpacket;

  temp_highpacket = (Data & 0xFFFF0000) >> 16;
  temp_lowpacket = (Data & 0x0000FFFF);

  digitalWrite(_chipSelect_Pin, LOW);

  temp_address = ((Address << 4) & 0xFFF0); //shift address  to align with cmd packet
  SPI.transfer16(temp_address);
  SPI.transfer16(temp_highpacket);
  SPI.transfer16(temp_lowpacket);

  digitalWrite(_chipSelect_Pin, HIGH);

}

/*
  Description: Reads 16bit data from register.
  Input: Register address
  Output: 16 bit data
*/

uint16_t ADE9000Class:: SPI_Read_16(uint16_t Address)
{
  uint16_t temp_address;
  uint16_t returnData;

  digitalWrite(_chipSelect_Pin, LOW);

  temp_address = (((Address << 4) & 0xFFF0) + 8);
  SPI.transfer16(temp_address);
  returnData = SPI.transfer16(0);

  digitalWrite(_chipSelect_Pin, HIGH);
  return returnData;
}

/*
  Description: Reads 32bit data from register.
  Input: Register address
  Output: 32 bit data
*/

uint32_t ADE9000Class:: SPI_Read_32(uint16_t Address)
{
  uint16_t temp_address;
  uint16_t temp_highpacket;
  uint16_t temp_lowpacket;
  uint32_t returnData;

  digitalWrite(_chipSelect_Pin, LOW);

  temp_address = (((Address << 4) & 0xFFF0) + 8);
  SPI.transfer16(temp_address);
  temp_highpacket = SPI.transfer16(0);
  temp_lowpacket = SPI.transfer16(0);

  digitalWrite(_chipSelect_Pin, HIGH);

  returnData = temp_highpacket << 16;
  returnData = returnData + temp_lowpacket;

  return returnData;

}
/*
  Description: Burst reads the content of waveform buffer. This function only works with resampled data. Configure waveform buffer to have Resampled data, and burst enabled (BURST_CHAN=0000 in WFB_CFG Register).
  Input: The starting address. Use the starting address of a data set. e.g 0x800, 0x804 etc to avoid data going into incorrect arrays.
       Read_Element_Length is the number of data sets to read. If the starting address is 0x800, the maximum sets to read are 512.
  Output: Resampled data returned in structure
*/

void ADE9000Class:: SPI_Burst_Read_Resampled_Noncoh_Wfb(uint16_t Address, uint16_t Read_Element_Length, ResampledWfbDataNoncoh *ResampledData)
{
  uint16_t temp;
  uint16_t i;
if(Address==0x800){
  i=0;
}
else
{

  i=128;
  Read_Element_Length=256;
}


  digitalWrite(_chipSelect_Pin, LOW);

  SPI.transfer16(((Address << 4) & 0xFFF0) + 8); //Send the starting address

  //burst read the data upto Read_Length
  for (i ; i < Read_Element_Length; i++)
  {
  //Serial.println("********set***********");
  ResampledData->IA_Resampled[i]=((SPI.transfer16(0)<<16)+SPI.transfer16(0));//IA
  ResampledData->VA_Resampled[i]=((SPI.transfer16(0)<<16)+SPI.transfer16(0));//VA
  ResampledData->IB_Resampled[i]=((SPI.transfer16(0)<<16)+SPI.transfer16(0));//IB
  ResampledData->VB_Resampled[i]=((SPI.transfer16(0)<<16)+SPI.transfer16(0));//VB
  ResampledData->IC_Resampled[i]=((SPI.transfer16(0)<<16)+SPI.transfer16(0));//IC
  ResampledData->VC_Resampled[i]=((SPI.transfer16(0)<<16)+SPI.transfer16(0));//VC
    
  }
   


  digitalWrite(_chipSelect_Pin, HIGH);
}
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

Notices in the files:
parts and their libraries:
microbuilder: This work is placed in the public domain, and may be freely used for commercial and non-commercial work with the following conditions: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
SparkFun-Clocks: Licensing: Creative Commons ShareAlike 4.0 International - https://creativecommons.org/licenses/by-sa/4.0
